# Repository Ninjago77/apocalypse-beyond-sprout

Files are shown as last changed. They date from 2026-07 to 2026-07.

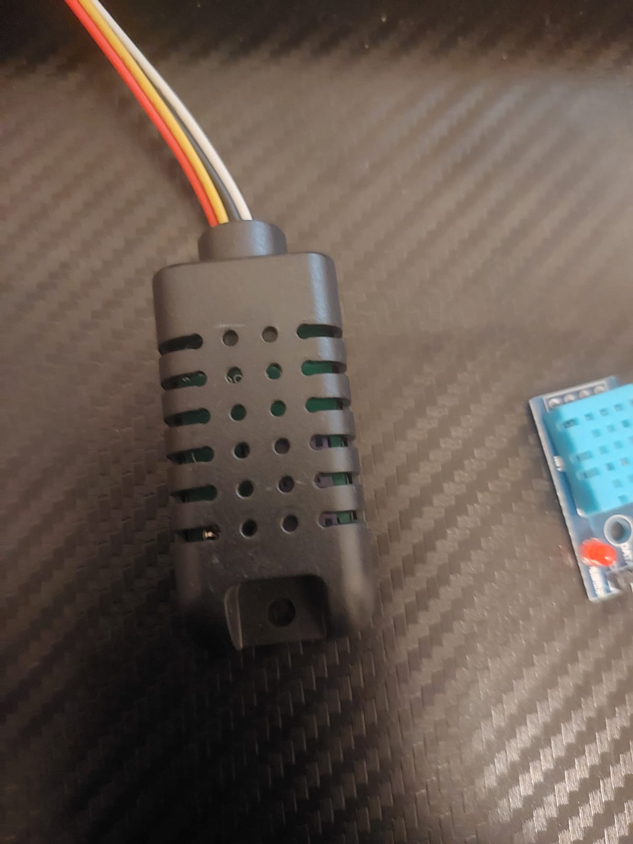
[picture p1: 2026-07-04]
images/WhatsApp Image 2026-07-03 at 22.15.47.jpeg

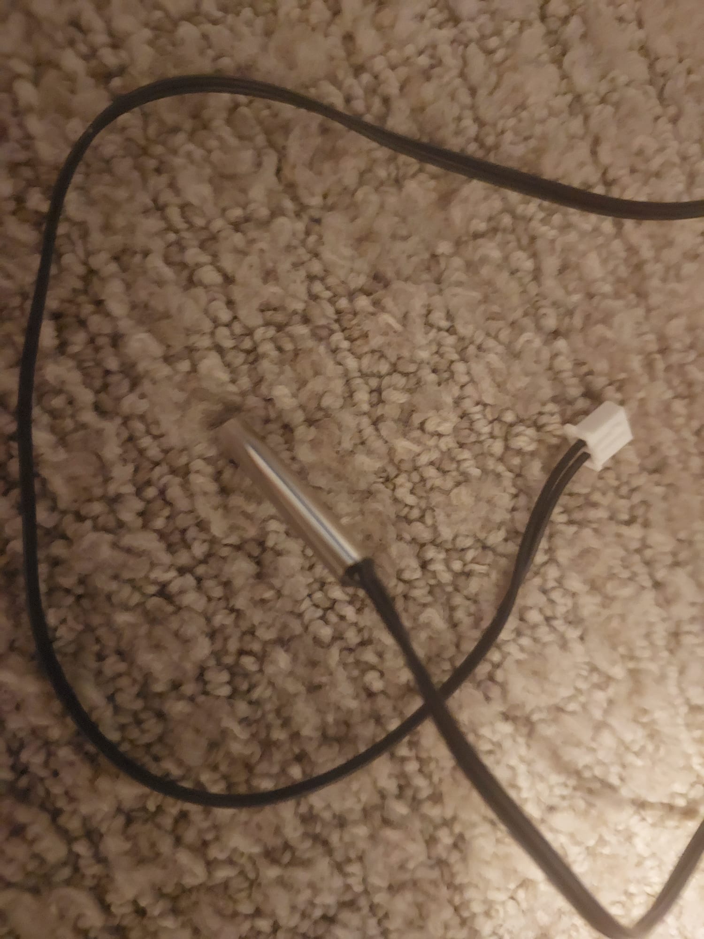
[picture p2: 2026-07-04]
images/WhatsApp Image 2026-07-03 at 22.15.47 (4).jpeg

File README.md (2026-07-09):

# Apocalypse Beyond - SPROUT | [Demo Video](https://github.com/Ninjago77/apocalypse-beyond-sprout/raw/refs/heads/main/videos/video%201.mp4)

A plant/bamboo caregiver with a custom oc on a display & numerous temperature sensors to make caring for your greenery easier!

## Gallery



















## Why?

Have you ever killed a plant by not caring for it properly?
Well, this little caretaker will give you all the info you need to take good care of your plant/bamboo!

## What?

It can identify whether your plant is ideally cared for, too dry, too cold, too wet or too hot using temperature & humidity sensors. It also has an OC indicating each of the different states your plant could be in, along with raw information from the sensors.

## List of Materials

| Component Name | Quantity | Required | Additional Notes |
| --- | --- | --- | --- |
| Raspberry Pi Pico | 1x | Yes | Main microcontroller unit for handling sensors and display. |
| Pushbutton | 2x | No (If you don't want input) | Configured as UP (GP17) and DOWN (GP15) navigation buttons, or to trigger sleep. |
| AMT1001 Temp & Humidity Sensor | 1x | No (but at least 1 Temp & 1 Humidity Sensor) | Only utilized for ambient humidity tracking outside the plant carer environment. |
| DHT11 Sensor | 1x | No (but at least 1 Temp & 1 Humidity Sensor) | Installed inside the plant carer enclosure, positioned safely above the water level. |
| Generic Thermistor | 1x | No (but atleast 1 Temp Sensor) | Submerged inside the water reservoir to track liquid temperature. |
| ST7735 1.8" RGB TFT Display | 1x | Yes | 128*160 resolution screen used for the user interface and data readouts. |
| NeoPixels | 4x | No | Addressable LED strip/array connected to GP23 for status indicators or lighting. |
| 10K Ohms Resistor | 2x | Yes | 1x used as a pull-up to 3V3 for the AMT1001, 1x used as a pull-down to GND for the thermistor. |
| Glass Bottle | 1x | Yes | Any bottle big enough should be fine, so long as the supports attach to it (You can modify the supports!) |

## AI Usage
AI used for Research into sensors & fusion troubles, as well as bitmap loading code.

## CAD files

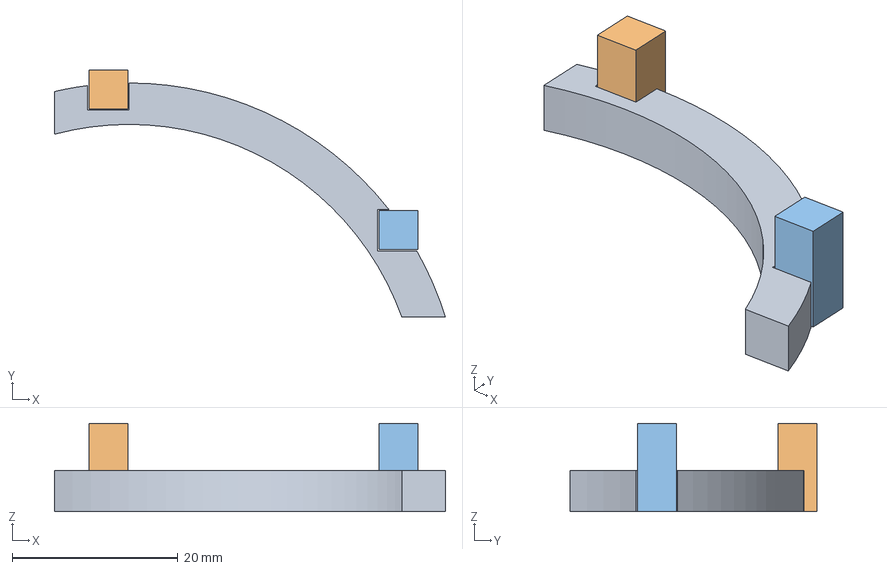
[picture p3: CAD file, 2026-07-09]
prints/complete assembly test tiny friction print.3mf
47.2 x 29.9 x 10.7 mm

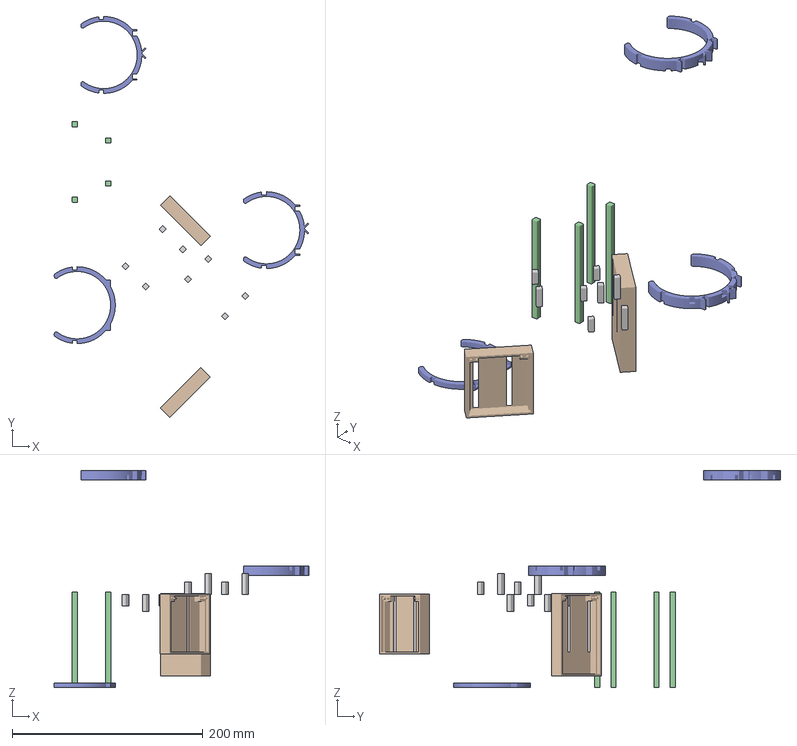
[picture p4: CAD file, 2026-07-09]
prints/complete assembly to print.3mf
266.6 x 420.1 x 227.5 mm

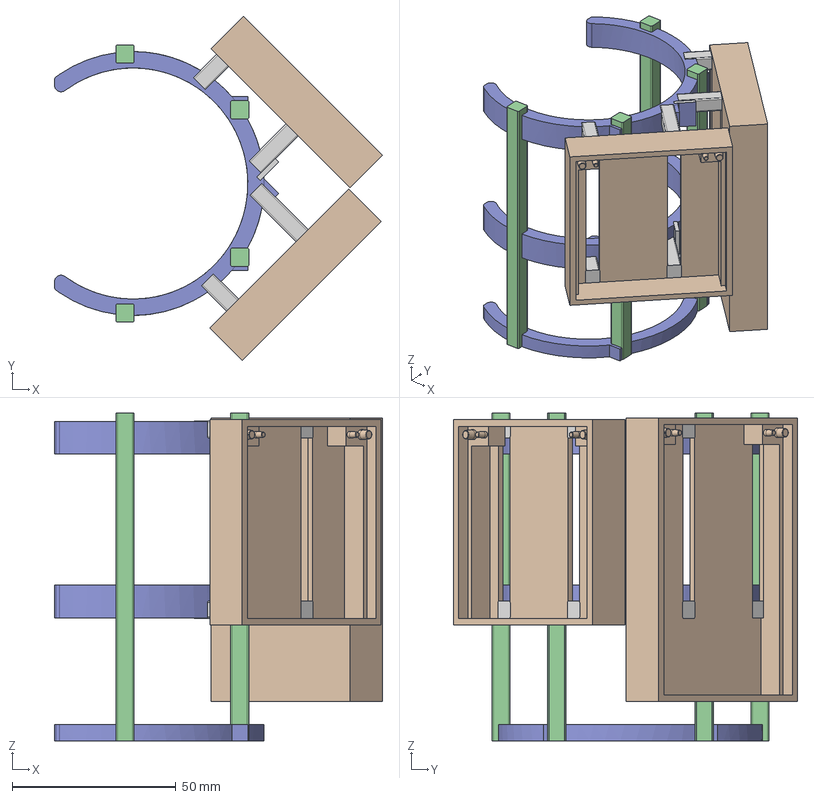
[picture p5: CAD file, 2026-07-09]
fusion_designs/complete assembly v3-dup.step
100.1 x 105.1 x 100.0 mm
test bottle bracket 2 v1
test bottle bracket 2 v1 (1)
perfboard bracket test v2(Mirror)

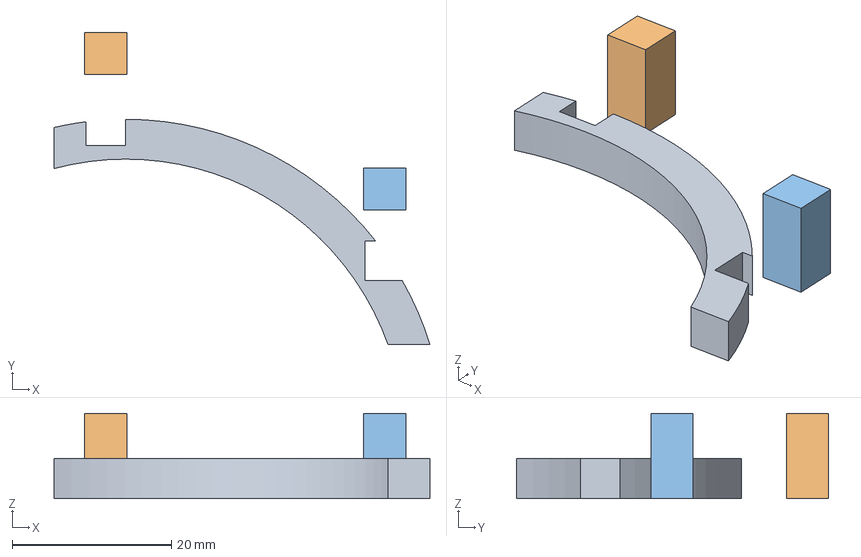
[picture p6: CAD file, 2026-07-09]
prints/complete assembly test tiny friction print 2.3mf
47.2 x 39.1 x 10.7 mm

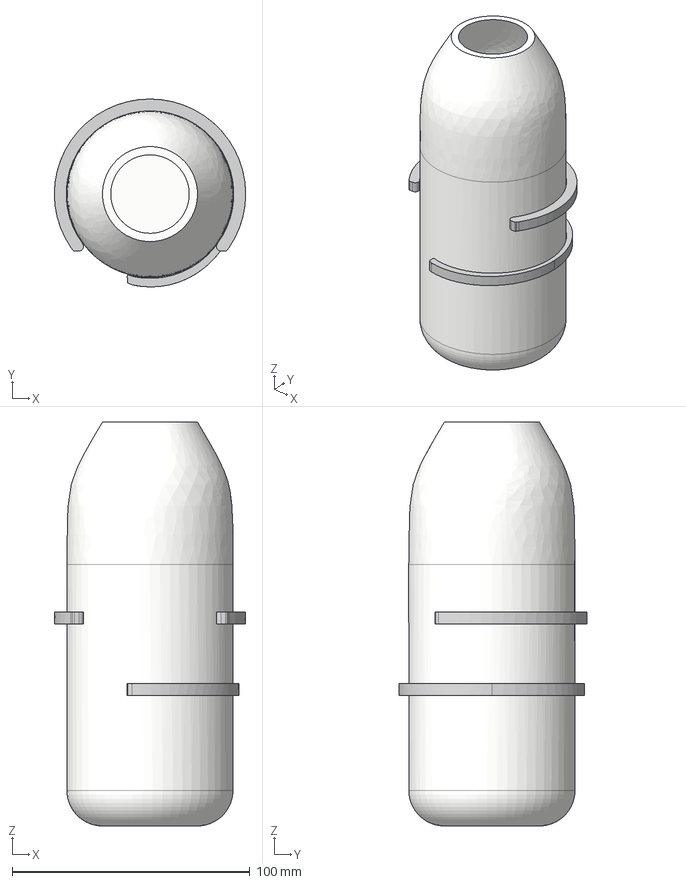
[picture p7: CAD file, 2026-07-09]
fusion_designs/test bottle bracket assembly v2.step
80.5 x 79.1 x 170.0 mm
bottle region
test bottle bracket
test bottle bracket 2

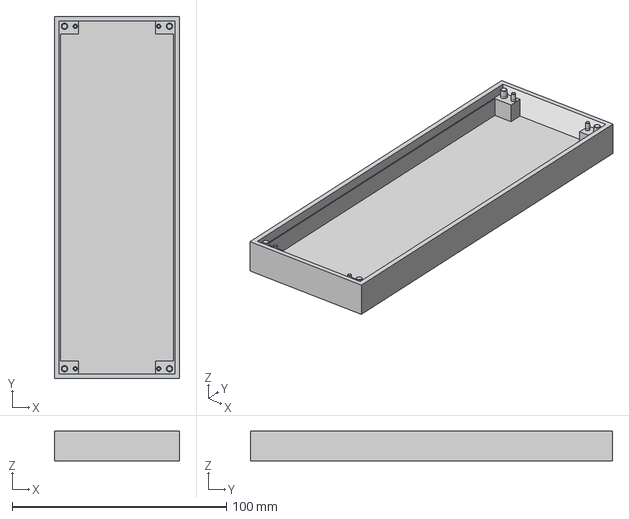
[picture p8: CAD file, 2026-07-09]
fusion_designs/full perfboard case v4.step
58.5 x 169.1 x 14.0 mm

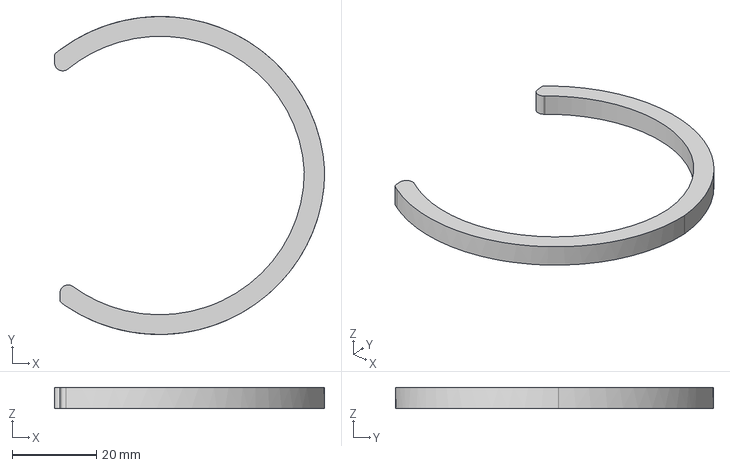
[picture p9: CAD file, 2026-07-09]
fusion_designs/test bottle bracket 5 v1.step
64.1 x 75.3 x 5.00 mm

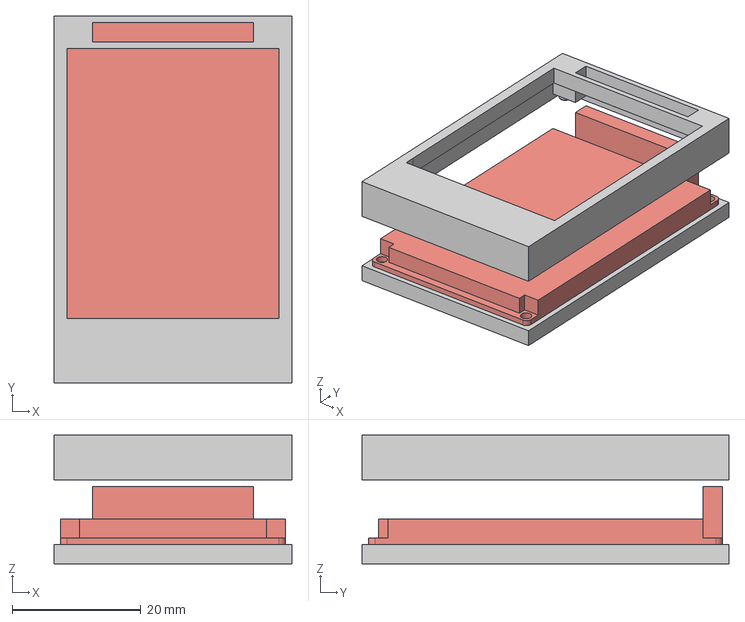
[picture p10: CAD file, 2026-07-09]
fusion_designs/display case v2.step
37.0 x 57.0 x 20.0 mm
display

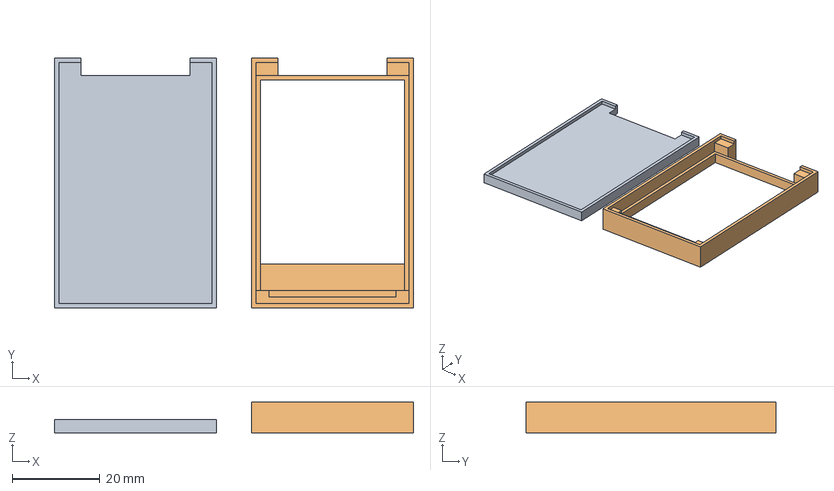
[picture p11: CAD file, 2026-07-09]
prints/display case 2.3mf
82.0 x 57.0 x 7.00 mm

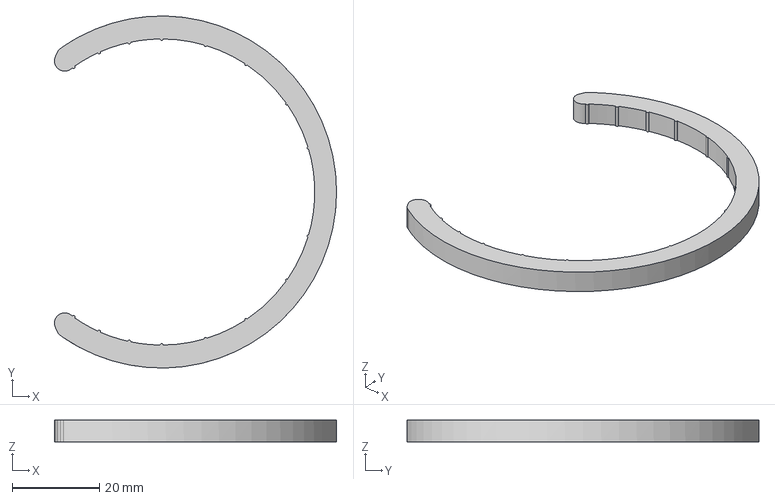
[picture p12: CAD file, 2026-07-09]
fusion_designs/test bottle bracket 3 v4.step
64.5 x 80.5 x 5.00 mm

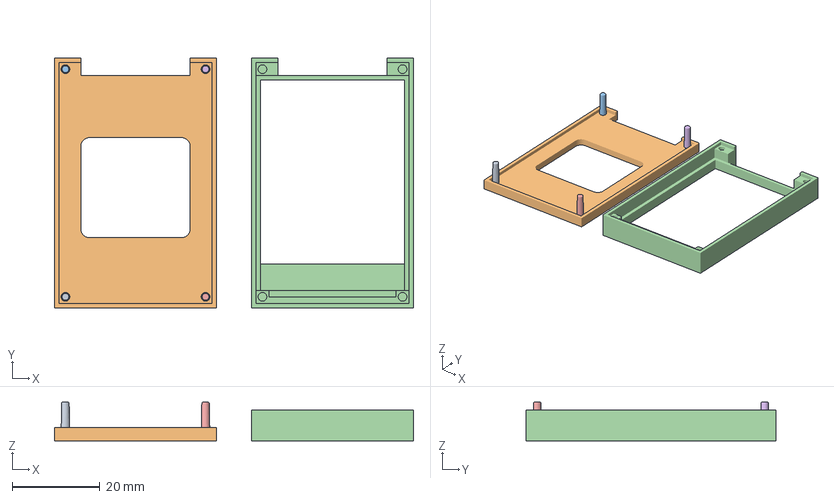
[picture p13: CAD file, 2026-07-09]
prints/display case 3.3mf
82.0 x 57.0 x 8.80 mm

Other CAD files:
prints/complete assembly wait.3mf
fusion_designs/complete assembly to print v3.step
fusion_designs/complete assembly test tiny friction print v3.step
fusion_designs/complete assembly v3.step
fusion_designs/complete assembly to print v3-dup.step
fusion_designs/assembly test friction print v3.step
fusion_designs/assembly test friction print v3-dup.step
fusion_designs/bottle region v6-dup.step
fusion_designs/bottle region v6.step
fusion_designs/display case 2 v3-dup.step
fusion_designs/display case 2 v3.step
fusion_designs/display case 3 v3-dup.step
fusion_designs/display case 3 v3.step
fusion_designs/display case v2-dup.step
fusion_designs/display v3-dup.step
fusion_designs/display v3.step
fusion_designs/perfboard bracket test v2.step
fusion_designs/split perf brackets 2 v3.step
fusion_designs/split perf brackets v2.step
fusion_designs/test bottle bracket 2 v1.step
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

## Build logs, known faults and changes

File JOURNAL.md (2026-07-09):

# MD Journal 
## June 2nd 2026 ~ 2 hours
I came up with the idea, when I was staring at a glass bottle on my desk & thinking about the Apocalypse hackathon in Toronto. So I did a little digging through my electronics to see whether I had sensors for anything related to plant growth, & I did.
WhatsApp Image 2026-07-03 at 22 15 47 (2)

So heres my idea, an A-tier project, about a plant monitoring system (because that's important during a Zombie Apocalypse), but why would that be A-tier with just a few sensors? Well, because there'll be a display with an animated plant character linked to the sensors themeselves!

## June 3rd 2026 Morning - 3 hours
I have a working display (st7735s) that I can use for this, along with a bunch of different types of sensors (later). This will be the main fragile part of the entire project:-
WhatsApp Image 2026-07-03 at 22 15 47 (3)

Next are the temperature & humidity sensors:-
WhatsApp Image 2026-07-03 at 22 15 47 (1)
WhatsApp Image 2026-07-03 at 22 15 47
WhatsApp Image 2026-07-03 at 22 15 47 (4)
 - **AMT1001** (the black one) - is a very precise temp & humidity sensor, but its a little big, so I'll be using it for the outer environment
 - **DHT11** (the blue one) - is a cheap temp & humidity sensor, plus I have multiple of them, so I'll be using it inside the glass, so I can swap it if one gets fried.
 - **Thermistor** (the silver rod) - is a waterproof temperature sensor (if i use a voltage divider), so I'll dip it all the way into the water (bamboo) or soil (plants).

## June 3rd 2026 Evening - 2 hours
I have prepared a plan for the project. The circuitry will be composed of a pico & perfboards to keep things organized. I also cut and sanded an old half perfboard to get this arangement:-
 - 
 - 

 I also bent this header pin to make the display cold-swappable as its pretty fragile, and is prone to breaking:-
 - 

## June 5th 2026 Morning - 4 hours
Now, that I have a plan in place, I need to get on Fusion & start working, so that's what I did, I modeled the bottle:-
  - 
And made it an actual bottle:
 - 
I don't have a 3d model for the perfboards, so I took a breadboard one I found:-
 - 
& made it into a perfboard shape:
 - 

I also need to make a removable clip to attach the circuitry and sensors to the bottle & remove them when needed, so I made a test bottle bracket (slightly oval to allow for clipping):
 - 
 
I'm also 3d printing this right away, so that I have a working (or theoretically) working clip. Here's what the assembly should look like:-
 - 

## June 5th 2026 Evening - 6 hours
Here is the test print in Real Life:-
 - 
Clips on well, sticks with friction, but it's pretty weak.
So I redid it again:-
 - 
The one above is the new one:-
 - 
 
 And then I sent it off for printing, while I started designing the display's cover to prevent it from breaking, or to be more specific, started designing the display first:-
  - 

By then, the print was done, so I tested it, and the "attaching force" was perfect & strong, but the holding friction was only on the ends & not throughout, so the clip would slide down with any weight:-
 - 

So I modified the test bracket again, making it more of a circle than an eclipse, added a bunch of studs:-
 - 
& sent it off for printing again.

Then, I got to work on making the display's case:-
 - 
Since it was looking pretty good, & I was proud of it, I sent it to print.

I got em both back, and the display case wasn't exactly nice, the studs were too thick & the rounded edges where also stopping it from fitting, so I need to redesign it:-
 - 

The new clip, was actually worse, less pads of contact and it wasn't even strong:-
 - 

## June 6th Morning 2026 - 6 hours

 So I designed a new display case without the roundiness and pads & sent it of for printing:-
  - 

 Now I have to redesign and stretch the seconf cilp model, & whiile I was doing that, the print was done:-
  - 
  - 
The top fit perfectly, the bottom needs to have a gap, but it was a success!

I just completed the new bottle bracket, so here it is & I sent it for printing:-
 - 

And here is the new & friction fitted (hopefully), case:-
 - 

## June 6th Evening 2026 - 

# REST OF JOURNAL TBD, WORK FOR June 6th, 7th & 8th 2026

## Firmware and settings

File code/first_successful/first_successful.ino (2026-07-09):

#include <SPI.h>
#include <Adafruit_GFX.h>
#include <Adafruit_ST7735.h>
#include <DHT.h>
#include <Adafruit_NeoPixel.h>
#include <stdio.h> // For standard C file I/O

// ---------------- Pins & Constants ----------------
#define BTN_UP 17
#define BTN_DOWN 15

#define DHT_PIN 14
#define DHT_TYPE DHT11
#define THERM_PIN 26      
#define AMT_HUM_PIN 28    
#define AMT_TEMP_PIN 27   

// TFT Display Pins
#define TFT_SCL 6 // SCK
#define TFT_SDA 7 // MOSI
#define TFT_RST 8
#define TFT_DC  9
#define TFT_CS  10
#define TFT_BLK 11

#define NEO_PIN 23
#define NUM_PIXELS 1 





// b_cold  60 x 60  (RGB565)
const uint16_t b_cold[] PROGMEM = {
  0x0000, 0x0000, 0x0000, 0x0000, 0x0000, 0x0000, 0x0000, 0x0000, 0x0000, 0x0000, 0x0000, 0x0000,
  0x0000, 0x0000, 0x0000, 0x0000, 0x0000, 0x0000, 0x0000, 0x0000, 0x0000, 0x0000, 0x0000, 0x0000,
  0x0000, 0x0000, 0x0000, 0x0000, 0x0000, 0x0000, 0x0000, 0x0000, 0x0000, 0x0000, 0x0000, 0x0000,
  0x0000, 0x0000, 0x0000, 0x0000, 0x0000, 0x0000, 0x0000, 0x0000, 0x0000, 0x0000, 0x0000, 0x0000,
  0x0000, 0x0000, 0x0000, 0x0000, 0x0000, 0x0000, 0x0000, 0x0000, 0x0000, 0x0000, 0x0000, 0x0000,
  0x0000, 0x0000, 0x0000, 0x0000, 0x0000, 0x0000, 0x0000, 0x0000, 0x0000, 0x0000, 0x0000, 0x0000,
  0x0000, 0x0000, 0x0000, 0x0000, 0x0000, 0x0000, 0x0000, 0x0000, 0x0000, 0x0000, 0x0000, 0x0000,
  0x0000, 0x0000, 0x0000, 0x0000, 0x0000, 0x0000, 0x0000, 0x0000, 0x0000, 0x0000, 0x0000, 0x0000,
  0x0000, 0x0000, 0x0000, 0x0000, 0x0000, 0x0000, 0x0000, 0x0000, 0x0000, 0x0000, 0x0000, 0x0000,
  0x0000, 0x0000, 0x0000, 0x0000, 0x0000, 0x0000, 0x0000, 0x0000, 0x0000, 0x0000, 0x0000, 0x0000,
  0x0000, 0x0000, 0x0000, 0x0000, 0x0000, 0x0000, 0x0000, 0x0000, 0x0000, 0x0000, 0x0000, 0x0000,
  0x0000, 0x0000, 0x0000, 0x0000, 0x0000, 0x0000, 0x0000, 0x0000, 0x0000, 0x7E58, 0x0000, 0x0000,
  0x0000, 0x0000, 0x44E6, 0x44E6, 0x7E58, 0x7E58, 0x0000, 0x0000, 0x0000, 0x0000, 0x0000, 0x0000,
  0x7E58, 0x7E58, 0x0000, 0x0000, 0x0000, 0x0000, 0x0000, 0x0000, 0x0000, 0x0000, 0x0000, 0x0000,
  0x0000, 0x0000, 0x0000, 0x0000, 0x0000, 0x0000, 0x0000, 0x0000, 0x0000, 0x0000, 0x0000, 0x0000,
  0x0000, 0x0000, 0x0000, 0x0000, 0x0000, 0x0000, 0x0000, 0x0000, 0x0000, 0x0000, 0x0000, 0x0000,
  0x0000, 0x0000, 0x0000, 0x0000, 0x0000, 0x0000, 0x0000, 0x0000, 0x0000, 0x0000, 0x14E0, 0x0000,
  0x0000, 0x44E6, 0x44E6, 0x44E6, 0x0000, 0x0000, 0x0000, 0x0000, 0x0000, 0x44E6, 0x44E6, 0x44E6,
  0x44E6, 0x7E58, 0x0000, 0x0000, 0x0000, 0x0000, 0x0000, 0x0000, 0x0000, 0x0000, 0x0000, 0x0000,
  0x0000, 0x0000, 0x0000, 0x0000, 0x0000, 0x0000, 0x0000, 0x0000, 0x0000, 0x0000, 0x0000, 0x0000,
  0x0000, 0x0000, 0x0000, 0x0000, 0x0000, 0x0000, 0x0000, 0x0000, 0x0000, 0x0000, 0x0000, 0x0000,
  0x0000, 0x0000, 0x0000, 0x14E0, 0x0000, 0xD3D7, 0xD3D7, 0xD3D7, 0xD3D7, 0xD3D7, 0x0000, 0x44E6,
  0x44E6, 0x44E6, 0x44E6, 0x44E6, 0x44E6, 0x44E6, 0x44E6, 0x44E6, 0x44E6, 0x44E6, 0x44E6, 0x0000,
  0x0000, 0x0000, 0x0000, 0x0000, 0x0000, 0x0000, 0x0000, 0x0000, 0x0000, 0x0000, 0x0000, 0x0000,
  0x0000, 0x0000, 0x0000, 0x0000, 0x0000, 0x0000, 0x0000, 0x0000, 0x0000, 0x0000, 0x0000, 0x0000,
  0x0000, 0x0000, 0x0000, 0x0000, 0x0000, 0x0000, 0x0000, 0x0000, 0x0000, 0x0000, 0x0000, 0x0000,
  0xD3D7, 0xD3D7, 0xD3D7, 0x0000, 0x0000, 0xD3D7, 0xE1F8, 0xE1F8, 0xD3D7, 0xD3D7, 0x0000, 0x44E6,
  0x44E6, 0x44E6, 0x44E6, 0x44E6, 0x44E6, 0x44E6, 0x44E6, 0x44E6, 0x44E6, 0x44E6, 0x44E6, 0x44E6,
  0x44E6, 0x44E6, 0x44E6, 0x44E6, 0x0000, 0x0000, 0x0000, 0x0000, 0x0000, 0x0000, 0x0000, 0x0000,
  0x0000, 0x0000, 0x0000, 0x0000, 0x0000, 0x0000, 0x0000, 0x0000, 0x0000, 0x0000, 0x0000, 0x0000,
  0x0000, 0x0000, 0x0000, 0x0000, 0x0000, 0x0000, 0x0000, 0x0000, 0x0000, 0x0000, 0x0000, 0x0000,
  0xD3D7, 0xD3D7, 0xE1F8, 0xE1F8, 0xE1F8, 0xE1F8, 0x0000, 0xE1F8, 0xE1F8, 0x0000, 0x0000, 0x0000,
  0x0000, 0x44E6, 0x44E6, 0x44E6, 0x44E6, 0x44E6, 0x44E6, 0x44E6, 0x44E6, 0x44E6, 0x44E6, 0x44E6,
  0x44E6, 0x44E6, 0x44E6, 0x44E6, 0x44E6, 0x44E6, 0x44E6, 0x44E6, 0x44E6, 0x0000, 0x0000, 0x0000,
  0x0000, 0x0000, 0x0000, 0x0000, 0x0000, 0x0000, 0x0000, 0x0000, 0x0000, 0x0000, 0x0000, 0x0000,
  0x0000, 0x0000, 0x0000, 0x0000, 0x0000, 0x0000, 0x0000, 0x0000, 0x0000, 0x0000, 0x0000, 0x0000,
  0x0000, 0xD3D7, 0xD3D7, 0xE1F8, 0x0000, 0xFFAE, 0xFFAE, 0xFFAE, 0x0000, 0xE1F8, 0xE1F8, 0xD3D7,
  0xD3D7, 0x0000, 0x44E6, 0x44E6, 0x44E6, 0x44E6, 0x44E6, 0x44E6, 0x44E6, 0x44E6, 0x44E6, 0x44E6,
  0x44E6, 0x44E6, 0x44E6, 0x44E6, 0x44E6, 0x44E6, 0x44E6, 0x44E6, 0x44E6, 0x44E6, 0x44E6, 0x44E6,
  0x7E58, 0x0000, 0x0000, 0x0000, 0x0000, 0x0000, 0x0000, 0x0000, 0x0000, 0x0000, 0x0000, 0x0000,
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
};
const int b_cold_width  = 60;
const int b_cold_height = 60;
// b_hot  60 x 60  (RGB565)
const uint16_t b_hot[] PROGMEM = {
  0x0000, 0x0000, 0x0000, 0x0000, 0x0000, 0x0000, 0x0000, 0x0000, 0x0000, 0x0000, 0x0000, 0x0000,
  0x0000, 0x0000, 0x0000, 0x0000, 0x0000, 0x0000, 0x0000, 0x0000, 0x0000, 0x0000, 0x0000, 0x0000,
  0x0000, 0x0000, 0x0000, 0x0000, 0x0000, 0x0000, 0x0000, 0x0000, 0x0000, 0x0000, 0x0000, 0x0000,
  0x0000, 0x0000, 0x0000, 0x0000, 0x0000, 0xFE60, 0xEFE0, 0xFE60, 0xFE60, 0xEFE0, 0xEFE0, 0xEFE0,
  0xEFE0, 0xEFE0, 0xEFE0, 0xEFE0, 0xEFE0, 0xEFE0, 0xEFE0, 0xEFE0, 0xEFE0, 0xEFE0, 0xEFE0, 0xEFE0,
  0x0000, 0x0000, 0x0000, 0x0000, 0x0000, 0x0000, 0x0000, 0x0000, 0x0000, 0x0000, 0x0000, 0x0000,
  0x0000, 0x0000, 0x0000, 0x0000, 0x0000, 0x0000, 0x0000, 0x0000, 0x0000, 0x0000, 0x0000, 0x0000,
  0x0000, 0x0000, 0x0000, 0x0000, 0x0000, 0x0000, 0x0000, 0x0000, 0x0000, 0x0000, 0x0000, 0x0000,
  0x0000, 0x0000, 0xFE60, 0xFE60, 0xFE60, 0xFE60, 0xEFE0, 0xEFE0, 0xFE60, 0xEFE0, 0xEFE0, 0xEFE0,
  0xEFE0, 0xEFE0, 0xEFE0, 0xEFE0, 0xEFE0, 0xEFE0, 0xEFE0, 0xEFE0, 0xEFE0, 0xEFE0, 0xEFE0, 0xEFE0,
  0x0000, 0x0000, 0x0000, 0x0000, 0x0000, 0x0000, 0x0000, 0x0000, 0x0000, 0x0000, 0x0000, 0x0000,
  0x0000, 0x0000, 0x0000, 0x0000, 0x0000, 0x0000, 0x0000, 0x0000, 0x0000, 0x0000, 0x0000, 0x0000,
  0x0000, 0x0000, 0x0000, 0x0000, 0x0000, 0x0000, 0x0000, 0x0000, 0x0000, 0x0000, 0x0000, 0x0000,
  0x0000, 0x0000, 0x0000, 0x0000, 0x0000, 0xFE60, 0xEFE0, 0xEFE0, 0xFE60, 0xEFE0, 0xEFE0, 0xEFE0,
  0xEFE0, 0xEFE0, 0xEFE0, 0xEFE0, 0xEFE0, 0xEFE0, 0xEFE0, 0xEFE0, 0xEFE0, 0xEFE0, 0xEFE0, 0xEFE0,
  0x0000, 0x0000, 0x0000, 0x0000, 0x0000, 0x0000, 0x0000, 0x0000, 0x0000, 0x0000, 0x0000, 0x0000,
  0x0000, 0x0000, 0x0000, 0x0000, 0x0000, 0x0000, 0x0000, 0x0000, 0x0000, 0x0000, 0x0000, 0x0000,
  0x0000, 0x0000, 0x0000, 0x0000, 0x0000, 0x0000, 0x0000, 0x0000, 0x0000, 0x0000, 0x0000, 0x0000,
  0x0000, 0x0000, 0x0000, 0x0000, 0x0000, 0xEFE0, 0xFE60, 0xFE60, 0xFE60, 0xFE60, 0xFE60, 0xEFE0,
  0xEFE0, 0xEFE0, 0xEFE0, 0xEFE0, 0xEFE0, 0xEFE0, 0xEFE0, 0xEFE0, 0xEFE0, 0xEFE0, 0xEFE0, 0xEFE0,
  0x0000, 0x0000, 0x0000, 0x0000, 0x0000, 0x0000, 0x0000, 0x0000, 0x0000, 0x0000, 0x0000, 0x0000,
  0x0000, 0x0000, 0x0000, 0x0000, 0x0000, 0x0000, 0x0000, 0x0000, 0x0000, 0x0000, 0x0000, 0x0000,
  0x0000, 0x0000, 0x0000, 0x0000, 0x0000, 0x0000, 0x0000, 0x0000, 0x0000, 0x0000, 0x0000, 0x0000,
  0x0000, 0x0000, 0x0000, 0x0000, 0xFE60, 0xFE60, 0xFE60, 0xFE60, 0xFE60, 0xEFE0, 0xEFE0, 0xEFE0,
  0xEFE0, 0xEFE0, 0xEFE0, 0xEFE0, 0xEFE0, 0xEFE0, 0xEFE0, 0xEFE0, 0xEFE0, 0xEFE0, 0xEFE0, 0xEFE0,
  0x0000, 0x0000, 0x0000, 0x0000, 0x0000, 0x0000, 0x0000, 0x0000, 0x0000, 0x0000, 0x0000, 0x0000,
  0x0000, 0x0000, 0x0000, 0x0000, 0x0000, 0x0000, 0x0000, 0x0000, 0x0000, 0x14E0, 0x0000, 0x0000,
  0x0000, 0x0000, 0x14E0, 0x14E0, 0x14E0, 0x14E0, 0x0000, 0x0000, 0x0000, 0x0000, 0x0000, 0x0000,
  0x14E0, 0x0000, 0x0000, 0xFE60, 0x0000, 0x0000, 0x0000, 0x0000, 0xEFE0, 0xEFE0, 0xFE60, 0xFE60,
  0xFE60, 0xEFE0, 0xEFE0, 0xEFE0, 0xEFE0, 0xEFE0, 0xEFE0, 0xEFE0, 0xEFE0, 0xEFE0, 0xEFE0, 0xEFE0,
  0x0000, 0x0000, 0x0000, 0x0000, 0x0000, 0x0000, 0x0000, 0x0000, 0x0000, 0x0000, 0x0000, 0x0000,
  0x0000, 0x0000, 0x0000, 0x0000, 0x0000, 0x0000, 0x0000, 0x0000, 0x0000, 0x0000, 0x14E0, 0x0000,
  0x0000, 0x14E0, 0x14E0, 0x14E0, 0x0000, 0x0000, 0x0000, 0x0000, 0x0000, 0x14E0, 0x14E0, 0x14E0,
  0x14E0, 0x0000, 0x0000, 0x0000, 0x0000, 0x14E0, 0x0000, 0x0000, 0xFE60, 0xFE60, 0xFE60, 0xFE60,
  0xEFE0, 0xEFE0, 0xFE60, 0xFE60, 0xEFE0, 0xEFE0, 0xEFE0, 0xEFE0, 0xEFE0, 0xEFE0, 0xEFE0, 0xEFE0,
  0x0000, 0x0000, 0x0000, 0x0000, 0x0000, 0x0000, 0x0000, 0x0000, 0x14E0, 0x0000, 0x0000, 0x0000,
  0x0000, 0x0000, 0x0000, 0x14E0, 0x0000, 0xBD36, 0xBD36, 0xBD36, 0xBD36, 0xBD36, 0x0000, 0x14E0,
  0x14E0, 0x14E0, 0x14E0, 0x14E0, 0x14E0, 0x14E0, 0x14E0, 0x14E0, 0x14E0, 0x14E0, 0x14E0, 0x0000,
  0x0000, 0x14E0, 0x14E0, 0x14E0, 0x14E0, 0x14E0, 0x0000, 0xFE60, 0xFE60, 0x0000, 0x0000, 0xEFE0,
  0xEFE0, 0xFE60, 0xFE60, 0xFE60, 0xEFE0, 0xEFE0, 0xEFE0, 0xEFE0, 0xEFE0, 0xEFE0, 0xEFE0, 0xEFE0,
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
};
const int b_hot_width  = 60;
const int b_hot_height = 60;
// b_dry  60 x 60  (RGB565)
const uint16_t b_dry[] PROGMEM = {
  0x0000, 0x0000, 0x0000, 0x0000, 0x0000, 0x0000, 0x0000, 0x0000, 0x0000, 0x0000, 0x0000, 0x0000,
  0x0000, 0x0000, 0x0000, 0x0000, 0x0000, 0x0000, 0x0000, 0x0000, 0x0000, 0x0000, 0x0000, 0x0000,
  0x0000, 0x0000, 0x0000, 0x0000, 0x0000, 0x0000, 0x0000, 0x0000, 0x0000, 0x0000, 0x0000, 0x0000,
  0x0000, 0x0000, 0x0000, 0x0000, 0x0000, 0x0000, 0x0000, 0x0000, 0x0000, 0x0000, 0x0000, 0x0000,
  0x0000, 0x0000, 0x0000, 0x0000, 0x0000, 0x0000, 0x0000, 0x0000, 0x0000, 0x0000, 0x0000, 0x0000,
  0x0000, 0x0000, 0x0000, 0x0000, 0x0000, 0x0000, 0x0000, 0x0000, 0x0000, 0x0000, 0x0000, 0x0000,
  0x0000, 0x0000, 0x0000, 0x0000, 0x0000, 0x0000, 0x0000, 0x0000, 0x0000, 0x0000, 0x0000, 0x0000,
  0x0000, 0x0000, 0x0000, 0x0000, 0x0000, 0x0000, 0x0000, 0x0000, 0x0000, 0x0000, 0x0000, 0x0000,
  0x0000, 0x0000, 0x0000, 0x0000, 0x0000, 0x0000, 0x0000, 0x0000, 0x0000, 0x0000, 0x0000, 0x0000,
  0x0000, 0x0000, 0x0000, 0x0000, 0x0000, 0x0000, 0x0000, 0x0000, 0x0000, 0x0000, 0x0000, 0x0000,
  0x0000, 0x0000, 0x0000, 0x0000, 0x0000, 0x0000, 0x0000, 0x0000, 0x0000, 0x0000, 0x0000, 0x0000,
  0x0000, 0x0000, 0x0000, 0x0000, 0x0000, 0x0000, 0x0000, 0x0000, 0x0000, 0xFAC0, 0x0000, 0x0000,
  0x0000, 0x0000, 0xFAC0, 0xFAC0, 0xFAC0, 0xFAC0, 0x0000, 0x0000, 0x0000, 0x0000, 0x0000, 0x0000,
  0xFAC0, 0xFAC0, 0x0000, 0x0000, 0x0000, 0x0000, 0x0000, 0x0000, 0x0000, 0x0000, 0x0000, 0x0000,
  0x0000, 0x0000, 0x0000, 0x0000, 0x0000, 0x0000, 0x0000, 0x0000, 0x0000, 0x0000, 0x0000, 0x0000,
  0x0000, 0x0000, 0x0000, 0x0000, 0x0000, 0x0000, 0x0000, 0x0000, 0x0000, 0x0000, 0x0000, 0x0000,
  0x0000, 0x0000, 0x0000, 0x0000, 0x0000, 0x0000, 0x0000, 0x0000, 0x0000, 0x0000, 0xFAC0, 0x0000,
  0x0000, 0xFAC0, 0xFAC0, 0xFAC0, 0x0000, 0x0000, 0x0000, 0x0000, 0x0000, 0xFAC0, 0xFAC0, 0xFAC0,
  0xFAC0, 0xFAC0, 0x0000, 0x0000, 0x0000, 0x0000, 0x0000, 0x0000, 0x0000, 0x0000, 0x0000, 0x0000,
  0x0000, 0x0000, 0x0000, 0x0000, 0x0000, 0x0000, 0x0000, 0x0000, 0x0000, 0x0000, 0x0000, 0x0000,
  0x0000, 0x0000, 0x0000, 0x0000, 0x0000, 0x0000, 0x0000, 0x0000, 0x0000, 0x0000, 0x0000, 0x0000,
  0x0000, 0x0000, 0x0000, 0xFAC0, 0x0000, 0xD3D7, 0xD3D7, 0xD3D7, 0xD3D7, 0xD3D7, 0x0000, 0xFE60,
  0xFE60, 0xFE60, 0xFE60, 0xFAC0, 0xFE60, 0xEFE0, 0xEFE0, 0xEFE0, 0xFE60, 0xFE60, 0xFAC0, 0x0000,
  0x0000, 0x0000, 0x0000, 0x0000, 0x0000, 0x0000, 0x0000, 0x0000, 0x0000, 0x0000, 0x0000, 0x0000,
  0x0000, 0x0000, 0x0000, 0x0000, 0x0000, 0x0000, 0x0000, 0x0000, 0x0000, 0x0000, 0x0000, 0x0000,
  0x0000, 0x0000, 0x0000, 0x0000, 0x0000, 0x0000, 0x0000, 0x0000, 0x0000, 0x0000, 0x0000, 0x0000,
  0xD3D7, 0xD3D7, 0xD3D7, 0x0000, 0x0000, 0xD3D7, 0xE1F8, 0xE1F8, 0xD3D7, 0xD3D7, 0x0000, 0xEFE0,
  0xEFE0, 0xEFE0, 0xFE60, 0xFE60, 0xEFE0, 0xEFE0, 0xEFE0, 0xEFE0, 0xEFE0, 0xEFE0, 0xFE60, 0xFE60,
  0xFE60, 0xFE60, 0xEFE0, 0xEFE0, 0x0000, 0x0000, 0x0000, 0x0000, 0x0000, 0x0000, 0x0000, 0x0000,
  0x0000, 0x0000, 0x0000, 0x0000, 0x0000, 0x0000, 0x0000, 0x0000, 0x0000, 0x0000, 0x0000, 0x0000,
  0x0000, 0x0000, 0x0000, 0x0000, 0x0000, 0x0000, 0x0000, 0x0000, 0x0000, 0x0000, 0x0000, 0x0000,
  0xD3D7, 0xD3D7, 0xE1F8, 0xE1F8, 0xE1F8, 0xE1F8, 0x0000, 0xE1F8, 0xE1F8, 0x0000, 0x0000, 0x0000,
  0x0000, 0xEFE0, 0xEFE0, 0xEFE0, 0xEFE0, 0xEFE0, 0xEFE0, 0xEFE0, 0xEFE0, 0xEFE0, 0xEFE0, 0xEFE0,
  0xEFE0, 0xEFE0, 0xEFE0, 0xEFE0, 0xEFE0, 0xEFE0, 0xFE60, 0xFE60, 0xFAC0, 0x0000, 0x0000, 0x0000,
  0x0000, 0x0000, 0x0000, 0x0000, 0x0000, 0x0000, 0x0000, 0x0000, 0x0000, 0x0000, 0x0000, 0x0000,
  0x0000, 0x0000, 0x0000, 0x0000, 0x0000, 0x0000, 0x0000, 0x0000, 0x0000, 0x0000, 0x0000, 0x0000,
  0x0000, 0xD3D7, 0xD3D7, 0xE1F8, 0x0000, 0xFFAE, 0xFFAE, 0xFFAE, 0x0000, 0xE1F8, 0xE1F8, 0xD3D7,
  0xD3D7, 0x0000, 0xEFE0, 0xEFE0, 0xEFE0, 0xEFE0, 0xEFE0, 0xEFE0, 0xEFE0, 0xEFE0, 0xEFE0, 0xEFE0,
  0xEFE0, 0xEFE0, 0xEFE0, 0xEFE0, 0xEFE0, 0xEFE0, 0xEFE0, 0xEFE0, 0xFE60, 0xFAC0, 0xFAC0, 0xFAC0,
  0xFAC0, 0x0000, 0x0000, 0x0000, 0x0000, 0x0000, 0x0000, 0x0000, 0x0000, 0x0000, 0x0000, 0x0000,
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
};
const int b_dry_width  = 60;
const int b_dry_height = 60;
// b_normal  60 x 60  (RGB565)
const uint16_t b_normal[] PROGMEM = {
  0x0000, 0x0000, 0x0000, 0x0000, 0x0000, 0x0000, 0x0000, 0x0000, 0x0000, 0x0000, 0x0000, 0x0000,
  0x0000, 0x0000, 0x0000, 0x0000, 0x0000, 0x0000, 0x0000, 0x0000, 0x0000, 0x0000, 0x0000, 0x0000,
  0x0000, 0x0000, 0x0000, 0x0000, 0x0000, 0x0000, 0x0000, 0x0000, 0x0000, 0x0000, 0x0000, 0x0000,
  0x0000, 0x0000, 0x0000, 0x0000, 0x0000, 0x0000, 0x0000, 0x0000, 0x0000, 0x0000, 0x0000, 0x0000,
  0x0000, 0x0000, 0x0000, 0x0000, 0x0000, 0x0000, 0x0000, 0x0000, 0x0000, 0x0000, 0x0000, 0x0000,
  0x0000, 0x0000, 0x0000, 0x0000, 0x0000, 0x0000, 0x0000, 0x0000, 0x0000, 0x0000, 0x0000, 0x0000,
  0x0000, 0x0000, 0x0000, 0x0000, 0x0000, 0x0000, 0x0000, 0x0000, 0x0000, 0x0000, 0x0000, 0x0000,
  0x0000, 0x0000, 0x0000, 0x0000, 0x0000, 0x0000, 0x0000, 0x0000, 0x0000, 0x0000, 0x0000, 0x0000,
  0x0000, 0x0000, 0x0000, 0x0000, 0x0000, 0x0000, 0x0000, 0x0000, 0x0000, 0x0000, 0x0000, 0x0000,
  0x0000, 0x0000, 0x0000, 0x0000, 0x0000, 0x0000, 0x0000, 0x0000, 0x0000, 0x0000, 0x0000, 0x0000,
  0x0000, 0x0000, 0x0000, 0x0000, 0x0000, 0x0000, 0x0000, 0x0000, 0x0000, 0x0000, 0x0000, 0x0000,
  0x0000, 0x0000, 0x0000, 0x0000, 0x0000, 0x0000, 0x0000, 0x0000, 0x0000, 0x14E0, 0x0000, 0x0000,
  0x0000, 0x0000, 0x14E0, 0x14E0, 0x14E0, 0x14E0, 0x0000, 0x0000, 0x0000, 0x0000, 0x0000, 0x0000,
  0x14E0, 0x14E0, 0x0000, 0x0000, 0x0000, 0x0000, 0x0000, 0x0000, 0x0000, 0x0000, 0x0000, 0x0000,
  0x0000, 0x0000, 0x0000, 0x0000, 0x0000, 0x0000, 0x0000, 0x0000, 0x0000, 0x0000, 0x0000, 0x0000,
  0x0000, 0x0000, 0x0000, 0x0000, 0x0000, 0x0000, 0x0000, 0x0000, 0x0000, 0x0000, 0x0000, 0x0000,
  0x0000, 0x0000, 0x0000, 0x0000, 0x0000, 0x0000, 0x0000, 0x0000, 0x0000, 0x0000, 0x14E0, 0x0000,
  0x0000, 0x14E0, 0x14E0, 0x14E0, 0x0000, 0x0000, 0x0000, 0x0000, 0x0000, 0x14E0, 0x14E0, 0x14E0,
  0x14E0, 0x14E0, 0x0000, 0x0000, 0x0000, 0x0000, 0x0000, 0x0000, 0x0000, 0x0000, 0x0000, 0x0000,
  0x0000, 0x0000, 0x0000, 0x0000, 0x0000, 0x0000, 0x0000, 0x0000, 0x0000, 0x0000, 0x0000, 0x0000,
  0x0000, 0x0000, 0x0000, 0x0000, 0x0000, 0x0000, 0x0000, 0x0000, 0x0000, 0x0000, 0x0000, 0x0000,
  0x0000, 0x0000, 0x0000, 0x14E0, 0x0000, 0xD3D7, 0xD3D7, 0xD3D7, 0xD3D7, 0xD3D7, 0x0000, 0x14E0,
  0x14E0, 0x14E0, 0x14E0, 0x14E0, 0x14E0, 0x14E0, 0x14E0, 0x14E0, 0x14E0, 0x14E0, 0x14E0, 0x0000,
  0x0000, 0x0000, 0x0000, 0x0000, 0x0000, 0x0000, 0x0000, 0x0000, 0x0000, 0x0000, 0x0000, 0x0000,
  0x0000, 0x0000, 0x0000, 0x0000, 0x0000, 0x0000, 0x0000, 0x0000, 0x0000, 0x0000, 0x0000, 0x0000,
  0x0000, 0x0000, 0x0000, 0x0000, 0x0000, 0x0000, 0x0000, 0x0000, 0x0000, 0x0000, 0x0000, 0x0000,
  0xD3D7, 0xD3D7, 0xD3D7, 0x0000, 0x0000, 0xD3D7, 0xE1F8, 0xE1F8, 0xD3D7, 0xD3D7, 0x0000, 0x14E0,
  0x14E0, 0x14E0, 0x14E0, 0x14E0, 0x14E0, 0x14E0, 0x14E0, 0x14E0, 0x14E0, 0x14E0, 0x14E0, 0x14E0,
  0x14E0, 0x14E0, 0x14E0, 0x14E0, 0x0000, 0x0000, 0x0000, 0x0000, 0x0000, 0x0000, 0x0000, 0x0000,
  0x0000, 0x0000, 0x0000, 0x0000, 0x0000, 0x0000, 0x0000, 0x0000, 0x0000, 0x0000, 0x0000, 0x0000,
  0x0000, 0x0000, 0x0000, 0x0000, 0x0000, 0x0000, 0x0000, 0x0000, 0x0000, 0x0000, 0x0000, 0x0000,
  0xD3D7, 0xD3D7, 0xE1F8, 0xE1F8, 0xE1F8, 0xE1F8, 0x0000, 0xE1F8, 0xE1F8, 0x0000, 0x0000, 0x0000,
  0x0000, 0x14E0, 0x14E0, 0x14E0, 0x14E0, 0x14E0, 0x14E0, 0x14E0, 0x14E0, 0x14E0, 0x14E0, 0x14E0,
  0x14E0, 0x14E0, 0x14E0, 0x14E0, 0x14E0, 0x14E0, 0x14E0, 0x14E0, 0x14E0, 0x0000, 0x0000, 0x0000,
  0x0000, 0x0000, 0x0000, 0x0000, 0x0000, 0x0000, 0x0000, 0x0000, 0x0000, 0x0000, 0x0000, 0x0000,
  0x0000, 0x0000, 0x0000, 0x0000, 0x0000, 0x0000, 0x0000, 0x0000, 0x0000, 0x0000, 0x0000, 0x0000,
  0x0000, 0xD3D7, 0xD3D7, 0xE1F8, 0x0000, 0xFFAE, 0xFFAE, 0xFFAE, 0x0000, 0xE1F8, 0xE1F8, 0xD3D7,
  0xD3D7, 0x0000, 0x14E0, 0x14E0, 0x14E0, 0x14E0, 0x14E0, 0x14E0, 0x14E0, 0x14E0, 0x14E0, 0x14E0,
  0x14E0, 0x14E0, 0x14E0, 0x14E0, 0x14E0, 0x14E0, 0x14E0, 0x14E0, 0x14E0, 0x14E0, 0x14E0, 0x14E0,
  0x14E0, 0x0000, 0x0000, 0x0000, 0x0000, 0x0000, 0x0000, 0x0000, 0x0000, 0x0000, 0x0000, 0x0000,
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
};
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
void loop() {
  // Check Sleep Button
  if (digitalRead(BTN_DOWN) == LOW) {
    isSleeping = !isSleeping;
    forceDraw = true;
    delay(300); // Debounce
  }

  // Update sensors every 2 seconds
  if (millis() - lastUpdate > 2000 || forceDraw) {
    lastUpdate = millis();
    readSensors();
    determineMood();
    updateUI();
    forceDraw = false;
  }
}

// ---------------- Functions ----------------

void readSensors() {
  // 1. Read DHT11
  float t = dht.readTemperature();
  float h = dht.readHumidity();
  if (!isnan(t)) airTemp = t;
  if (!isnan(h)) airHum = h;

  // 2. Read Thermistor
  int adcWater = analogRead(THERM_PIN);
  if (adcWater > 0 && adcWater < 4095) {
    float rTherm = (40950000.0 / adcWater) - 10000.0;
    float steinhart = log(rTherm / 10000.0) / 3950.0;                   
    steinhart += 1.0 / (25.0 + 273.15);     
    waterTemp = (1.0 / steinhart) - 273.15; 
  }

  // 3. Read AMT1001 (Humidity portion)
  int adcHum = analogRead(AMT_HUM_PIN);
  outHum = (adcHum / 4095.0) * 100.0; 
}

void determineMood() {
  if (isSleeping) {
    currentMood = SLEEP;
  } 
  // Prioritize extreme temperatures first
  else if (airTemp > 30.0 || waterTemp > 30.0) {
    currentMood = HOT;
  } 
  else if (airTemp < 15.0 || waterTemp < 15.0) {
    currentMood = COLD;
  } 
  // Then check for extreme humidity/moisture
  else if (airHum > 75.0 || outHum > 75.0) {
    currentMood = WET;
  } 
  else if (airHum < 30.0 || outHum < 30.0) {
    currentMood = DRY;
  } 
  // If all is good, it's normal!
  else {
    currentMood = NORMAL;
  }
}

void updateUI() {
  // 1. Update the Screen only if the mood changed (or on startup)
  if (currentMood != lastMood || forceDraw) {
    
    // Draw the corresponding array instantly based on the mood
    switch(currentMood) {
      case NORMAL: 
        strip.fill(strip.Color(0, 255, 0)); // Green
        tft.drawRGBBitmap(10, 34, sprite_normal, 60, 60);
        break;
        
      case SLEEP: 
        strip.fill(strip.Color(10, 10, 50)); // Dim Blue
        tft.drawRGBBitmap(10, 34, sprite_sleep, 60, 60);
        break;
        
      case WET: 
        strip.fill(strip.Color(0, 255, 200)); // Cyan / Wet
        tft.drawRGBBitmap(10, 34, sprite_wet, 60, 60);
        break;

      case DRY: 
        strip.fill(strip.Color(255, 200, 0)); // Yellow/Brown / Dry
        tft.drawRGBBitmap(10, 34, sprite_dry, 60, 60);
        break;
        
      case HOT: 
        strip.fill(strip.Color(255, 50, 0)); // Orange/Red
        tft.drawRGBBitmap(10, 34, sprite_hot, 60, 60);
        break;
        
      case COLD: 
        strip.fill(strip.Color(100, 150, 255)); // Bright Icy Blue
        tft.drawRGBBitmap(10, 34, sprite_cold, 60, 60);
        break;
    }
    strip.show();
    lastMood = currentMood;
  }

  // 2. Draw Text Data (this updates every 2 seconds)
  tft.setCursor(85, 20);
  tft.setTextColor(ST77XX_CYAN, ST77XX_BLACK);
  tft.print("Bamboo Care");
  
  tft.setTextColor(ST77XX_WHITE, ST77XX_BLACK);
  
  tft.setCursor(85, 45); 
  tft.print("AirT: "); tft.print(airTemp, 1); tft.print("C  ");
  
  tft.setCursor(85, 60); 
  tft.print("AirH: "); tft.print(airHum, 1); tft.print("%  ");
  
  tft.setCursor(85, 75); 
  tft.print("WatT: "); tft.print(waterTemp, 1); tft.print("C  ");
  
  tft.setCursor(85, 90); 
  tft.print("OutH: "); tft.print(outHum, 1); tft.print("%  ");
}

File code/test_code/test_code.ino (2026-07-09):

#include <Adafruit_GFX.h>
#include <Adafruit_ST7735.h>
#include <Adafruit_NeoPixel.h>
#include <DHT.h>
#include <math.h>

// --- Pin Definitions ---
// TFT Display (ST7735)
#define TFT_SCLK  6  // Software SPI SCK
#define TFT_MOSI  7  // Software SPI TX/MOSI
#define TFT_RST   8  
#define TFT_DC    9  
#define TFT_CS    10 
#define TFT_BLK   11 

// NeoPixels
#define NEO_PIN   23 
#define NUM_PIXELS 4 

// Sensors
#define DHTPIN       14 // DHT11 Data Pin
#define DHTTYPE      DHT11 
#define PIN_THERM    26 // ADC0 - Generic Thermistor
#define PIN_AMT_TEMP 27 // ADC1 - AMT1001 White Wire
#define PIN_AMT_HUM  28 // ADC2 - AMT1001 Yellow Wire

// Initialize objects
Adafruit_NeoPixel pixels(NUM_PIXELS, NEO_PIN, NEO_GRB + NEO_KHZ800);
Adafruit_ST7735 tft = Adafruit_ST7735(TFT_CS, TFT_DC, TFT_MOSI, TFT_SCLK, TFT_RST);
DHT dht(DHTPIN, DHTTYPE);

// Variables
uint16_t currentHue = 0; 
unsigned long lastSensorRead = 0;

// Store sensor readings
float dhtTemp = 0, dhtHum = 0;
float amtTemp = 0, amtHum = 0;
float thermTemp = 0;

void setup() {
  Serial.begin(115200);

  // Set the Pico's ADC resolution to 12-bit (0-4095) for better accuracy
  analogReadResolution(12);

  // 1. Setup NeoPixels
  pixels.begin();
  pixels.setBrightness(50);
  pixels.show();

  // 2. Setup TFT Backlight
  pinMode(TFT_BLK, OUTPUT);
  digitalWrite(TFT_BLK, HIGH); 

  // 3. Initialize TFT Display
  tft.initR(INITR_BLACKTAB); 
  tft.setRotation(1); // Landscape mode
  tft.fillScreen(ST77XX_BLACK);

  // 4. Initialize DHT11
  dht.begin();
}

void loop() {
  // Read sensors every 2 seconds (The DHT11 is slow and requires 2s between reads)
  if (millis() - lastSensorRead >= 2000 || lastSensorRead == 0) {
    lastSensorRead = millis();

    // --- 1. Read DHT11 ---
    dhtTemp = dht.readTemperature();
    dhtHum = dht.readHumidity();

    // --- 2. Read Generic Thermistor (ADC0) ---
    // Wired: 3V3 -> NTC -> [ADC0] -> 10k -> GND
    float val0 = analogRead(PIN_THERM);
    if (val0 > 0 && val0 < 4095) {
      float rNtc0 = 10000.0 * (4095.0 / val0 - 1.0);
      // Steinhart-Hart calculation (Using standard B-value of 3950)
      thermTemp = (1.0 / (1.0 / 298.15 + (1.0 / 3950.0) * log(rNtc0 / 10000.0))) - 273.15;
    } else {
      thermTemp = NAN; // Error reading
    }

    // --- 3. Read AMT1001 Temperature (ADC1) ---
    float val1 = analogRead(PIN_AMT_TEMP);
    if (val1 > 10 && val1 < 4085) { 
      float rNtc1 = 10000.0 * val1 / (4095.0 - val1);
      amtTemp = (1.0 / (1.0 / 298.15 + (1.0 / 3435.0) * log(rNtc1 / 10000.0))) - 273.15;
    } else {
      // Instead of NAN, output the raw ADC value so we can see what the pin is doing!
      // If it says 4095 C on screen, the pin is stuck at 3.3V.
      // If it says 0 C on screen, the pin is shorted to Ground.
      amtTemp = val1; 
    }
    // --- 4. Read AMT1001 Humidity (ADC2) ---
    // AMT1001 outputs 0V to 3.0V linearly for 0% to 100% Humidity
    float val2 = analogRead(PIN_AMT_HUM);
    float vAdc2 = (val2 / 4095.0) * 3.3; // Convert digital 12-bit value back to voltage
    amtHum = vAdc2 / 0.03; // Datasheet formula: Humidity = Voltage / 0.03
  }

  // --- GENERATE RAINBOW COLORS ---
  uint32_t rgb32 = pixels.ColorHSV(currentHue, 255, 255);
  uint8_t r = (rgb32 >> 16) & 0xFF;
  uint8_t g = (rgb32 >>  8) & 0xFF;
  uint8_t b = rgb32 & 0xFF;

  // 1. UPDATE NEOPIXELS
  for(int i = 0; i < NUM_PIXELS; i++) {
    pixels.setPixelColor(i, rgb32);
  }
  pixels.show();

  // 2. UPDATE TFT DISPLAY
  uint16_t tftColor = tft.color565(r, g, b);
  tft.fillScreen(tftColor);

  uint16_t invColor = ~tftColor;
  // Passing the background color alongside the foreground prevents the text from tearing/flashing
  tft.setTextColor(invColor, tftColor); 
  tft.setTextSize(1);
  
  // Layout Variables (helps space the text cleanly)
  int y = 5;       // Starting Y position
  int dy = 15;     // Spacing between lines
  int dyGap = 5;   // Extra spacing between sensor sections
  
  tft.setCursor(5, y); tft.print("== DHT11 =="); y += dy;
  tft.setCursor(5, y); tft.print("Temp: "); tft.print(dhtTemp); tft.print(" C"); y += dy;
  tft.setCursor(5, y); tft.print("Hum : "); tft.print(dhtHum); tft.print(" %"); y += dy + dyGap;

  tft.setCursor(5, y); tft.print("== AMT1001 =="); y += dy;
  tft.setCursor(5, y); tft.print("Temp: "); tft.print(amtTemp); tft.print(" C"); y += dy;
  tft.setCursor(5, y); tft.print("Hum : "); tft.print(amtHum); tft.print(" %"); y += dy + dyGap;

  tft.setCursor(5, y); tft.print("== THERMISTOR =="); y += dy;
  tft.setCursor(5, y); tft.print("Temp: "); tft.print(thermTemp); tft.print(" C");

  // Increment hue to push the rainbow forward
  currentHue += 750; 
  delay(10);
}

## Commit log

2026-07-05 Revise JOURNAL.md with project updates
    Updated journal entries with additional details about project planning and sensor selection.
2026-07-06 Document June 5th 2026 evening progress and updates
    Added details about the June 5th 2026 evening work, including test prints and improvements to the clip design.
2026-07-09 Initialize README with project details and materials
    Added detailed project description, materials list, and usage information for the Apocalypse Beyond - SPROUT plant caregiver.
2026-07-09 bad to commit everything in one go. but I didnt keep track of time as fusion did
    [assembly test friction print v3-dup.step, assembly test friction print v3.step, bottle region v6-dup.step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]
